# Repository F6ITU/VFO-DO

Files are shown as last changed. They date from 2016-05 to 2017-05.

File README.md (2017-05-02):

VFO-DO
RF Generator, Kicad project

VFO-DO est un générateur HF couvrant de quelques kHz à 100 MHz.

Il s'agit d'une idée originale de Gene Marcus W3PM/GM4YRE
publiée dans un article de la revue QEX

http://www.arrl.org/files/file/QEX_Next_Issue/2015/Jul-Aug_2015/Marcus.pdf

Ce projet Kicad n'est que la transposition dudit projet. 

La propriété intellectuelle et les droits de publication appartiennent respectivement 
à l'auteur et à la société de publication mentionnés

Ce projet offre à chaque débutant en électronique ou en radioélectricité les éléments nécessaires
à la construction d'une source de fréquence stable (précise au Herz près, puisque pilotée par l'étalon césium
de l'essaim de satellites GPS)... et surtout simple à construire -à assembler serait le terme le plus exact.

Cette réalisation peut servir d'équipement de terrain, là ou le déplacement d'un oscillateur asservi
-équipement fragile et coûteux- est inenvisageable. C'est surtout une approche simple pour piloter un petit SDR ou remplacer le VFO 
d'un appareil radio traditionnel

Plus d'informations sur le module oscillateur à base de SiLabs Si5351 
https://learn.adafruit.com/adafruit-si5351-clock-generator-breakout?view=all

une seconde source de ce module 

https://www.sv1afn.com/si5351a.html
Attention : ce dernier module n'est pas "pin compatible" avec le précédent

Le firmware originel de l'auteur 
http://www.knology.net/~gmarcus/Si5351/Si5351_vfo_v5.ino.zip

Un émetteur-récepteur WSPR conçu par l'auteur et utilisant ledit VFO-DO
http://www.knology.net/~gmarcus/Si5351/Si5351A_WSPR_XCVR.pdf

NB : le coût du générateur gravite aux environ des 30 euros. 
Attention, le bruit de phase d'un tel générateur est assez important, et ne peut 
rivaliser avec un GPS-DO traditionnel.

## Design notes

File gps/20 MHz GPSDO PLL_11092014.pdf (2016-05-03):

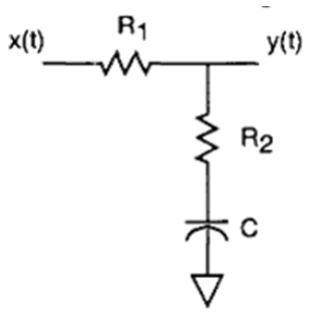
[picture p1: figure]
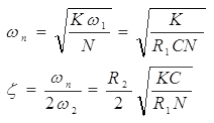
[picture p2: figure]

Pg 1 of 5 | K9IVB 11/08/2014

## 20 MHz GPSDO PLL

This is a preliminary document describing a GPSDO PLL that is to work with a ublox NEO-7 GPS receiver. Eventually it is desired to incorporate an Arduino uP to manage the startup with a simple display and a buffer board that will supply a suitable signal for reference frequency distribution employing 74HCT1G125 drivers.
The First PCB [1.7” x 1.7"] provides a PLL, an interface to the ublox GPS, an Arduino connection and a level converter for the serial communications. There is provision for a battery backup for the ublox NEO-7 that may be implemented in several different ways.
The PLL filter is described by the normal equations found below and exploited in a spreadsheet to be made available later.

### Second Order Passive Lead-Lag Filter

Also

is the phase detector gain in volts per radian | [(Power Supply/2])/[PI/2] = (Power Supply) / PI
is the VCO gain in radians per volt-second | 2*PI*(VCO Slope)
is the damping factor | [zeta]
is the natural frequency of the loop | = 2*PI*f
N is the loop frequency devisor
f is the loop frequency in Hz
K = | = [2 * (VCO Slope) * (Power Supply)] / N | NOTE: The PI's cancel
f | | C in F | | R2 | R1 | C in uF
0.16 | 1.005310 | 1.010647491 0.000470000 94.988610 | 2.575851 | 5,480.53 | 196,622.89 | 470
R1 | R2 | C | f
196000 | 6040 | 0.000470000 | 1.020842 | 1.448984 | 0.162472
K9IVB 10/18/2014
2 ωn | 1 τ | 2 τ

N

KV K p

Pg 2 of 5 | K9IVB 11/08/2014

After some additional reading, I have added another tab to the spreadsheet with the damping factor [zeta], ζ = 0.707. As it turns out you can achieve this condition by changing the R1 value to 200.0K and R2 to 3010 Ohms, = 0.7418; C still = 470 μF. Keeping the values of R1 =196.0K and C = 470 μF with R2 = 3.020 K by simply putting two of the 6.040K resistors in parallel and ζ = 0.7245, if you are interested in this value for ζ.
In my opinion, too many of the authors have put far too much emphasis on Floyd Gardner's mathematics and very little on the real world. Gardner shows best performance with ζ = 0.5 and has a "compromise" value of ζ = 0.707. These values reflect loops primarily used for an integer N synthesizer or signal recovery. We are doing neither and overshoot is undesirable, so ζ = 1.3 is number that I have chosen. Professor Long does differentiate in types of loops and suggests that even higher values of ζ may be used.
Another variable, of the few that are available is the loop natural frequency. This design can be considered a high gain loop, because of the VCO slope, the loop divisor N is only 10 and the reference frequency is 2.0MHz. When using reference frequencies of 1pps or up to 10KHz the loop natural frequency needs to be very small and preferably several orders of magnitude less than the reference frequency. I have chosen to keep this value small and still sub Hz at 0.16Hz. It is possible that it could be raised 10 to 100 times without affecting performance. Raising this value would bring the value of C near a level where a high performance film capacitor would be able to replace the Tantalum used for C1.
I will put more info on the web site after I get one built.

### References:

Best, Rolland E. Phase Locked Loops Design, Simulation, and Applications, Fifth Edition, New York, McGraw-Hill, 2003 Gardner, F.M., Phaselock Techniques, Second Edition, New York, NY, John Wiley and Sons, 1979.

### Long. Prof Steve, PLL_intro_594a_s05.pdf, UCSB/ECE Department, April 27, 2005

Stevens, Donald R., PHASE-LOCKED LOOPS FOR WIRELESS COMMUNICATIONS Digital, Analog and Optical

### Implementations, Second Edition, NEW YORK, KLUWER ACADEMIC PUBLISHERS, 2002

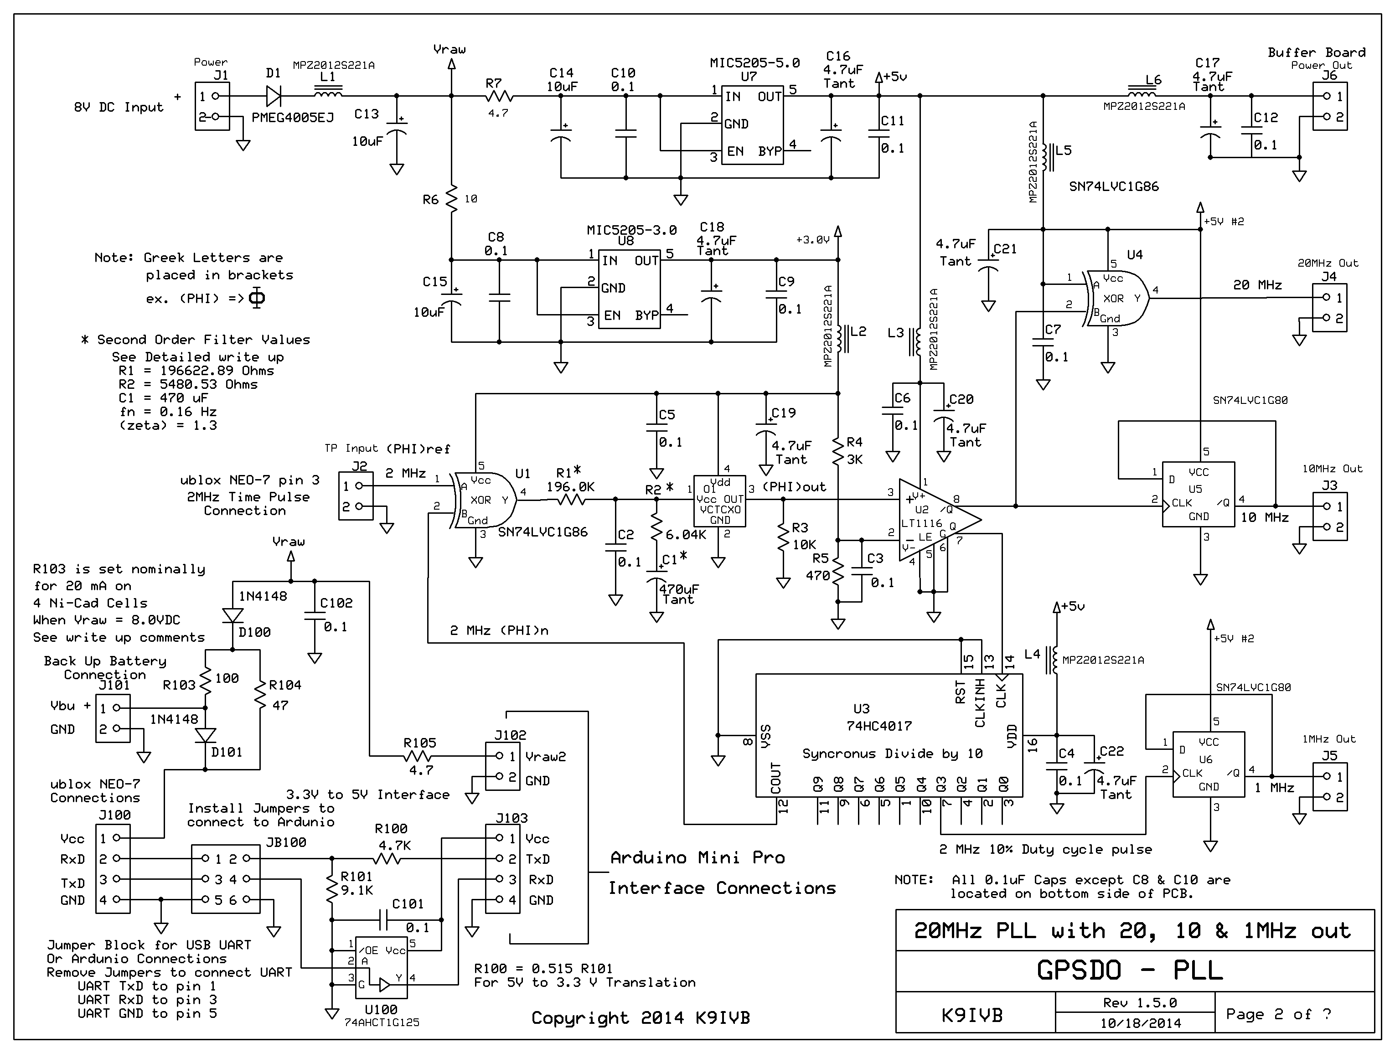
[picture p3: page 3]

Pg 3 of 5 | K9IVB 11/08/2014

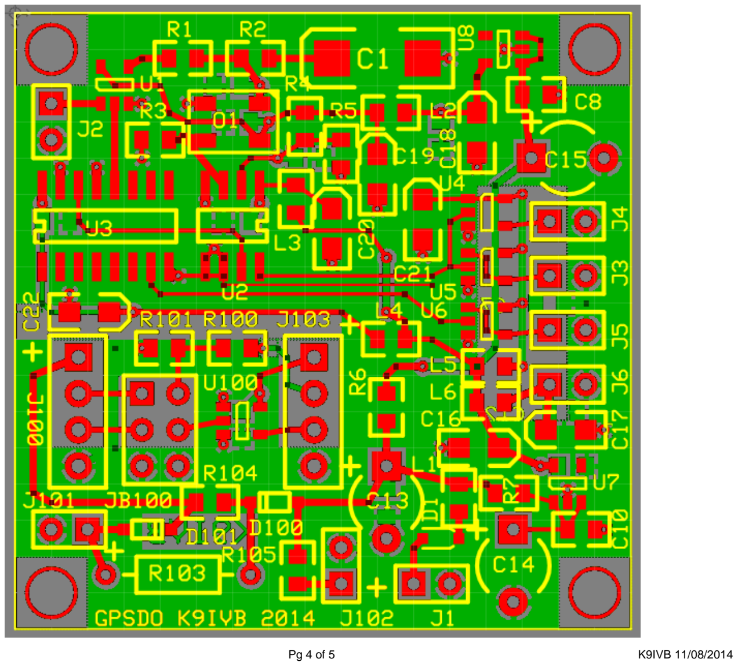
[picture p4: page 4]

Pg 4 of 5 | K9IVB 11/08/2014

Pg 5 of 5 | K9IVB 11/08/2014
GPSDO-PLL BOM | K9IVB 10/18/2014
Ref Des | Value | Description | Part Number | Mfg | PAD | Mouser | Qty
C1 | 470uF

Tantalum Capacitors -
Solid SMD 6.3V 470uF
10% "Y" Case | TAJY477K006RNJ | AVX | [7343] | 581-TAJY477K006RNJ | 1
C2, 3, 4, 5, 6,
7, 8, 9, 10,
11, 12, 101,
102 | 0.1

Multilayer Ceramic
Capacitors MLCC -
SMD/SMT 25volts 0.1uF
X7R 10% | C0805C104K3R | KEMET | [0805] | 80-C0805C104K3R | 13
C13, 14, 15 | 10uF | Aluminum Electrolytic
| | Capacitors - Leaded
| | 16volts 10uF 4X7mm
| | L/S=5.0mm Ammo
Crmp | EEA-GA1C100B | Panasonic 0.2" LS | 667-EEAGA1C100B | 3

C16, 17, 18,
19, 20, 21, 22 4.7uF Tant
| | Tantalum Capacitors -
| | Solid SMD 10V 4.7uF
10% "A" | T491A475K010AT | KEMET | 1206 | 80-T491A475K010 | 7
D1 | PMEG4005EJ | Schottky Diodes &
Rectifiers 40V 0.5A | PMEG4005EJ,115 | NXP | SOD-323 | 771-PMEG4005EJ-T/R | 1
D100, 101 | 1N4148 | 1N4148, SOD-323F | Fairchild | SOD-123 | 512-1N4148WS | 2
J1, 2, 3, 4, 5,
6, 101, 102 | | 1x2 .100" Header | | | | 8
J100, 103 | | 1x4 .100" Header | | | | 2
JB100 | | 2x3 .100" Header | | | | 1
L1, 2, 3, 4, 5,
6 | MPZ2012S221A | FERRITE CHIP 220
OHM 3A | MPZ2012S221A | [0805] | 810-MPZ2012S221A | 6
O1 | VCTCXO | ASVTX-09-20.000MHz-T | 815-ASVTX-09-20.0MT | 1
R1 | 196K | Thin Film Resistors -
| | SMD 0805 196Kohm
0.1% 25ppm | ERA-6AEB1963V | Panasonic | 667-ERA-6AEB1963V | 1
R2 | 6.040K | Thin Film Resistors -
| | SMD 0805 6.04Kohm
0.1% 25ppm | ERA-6AEB6041V | Panasonic | 667-ERA-6AEB6041V | 1
R3 | 10K | Thick Film Resistors -
| | SMD 1/10watts
10Kohms 5% | RK73B1JTTDD103J | KOA Speer [0805] | 660-RK73B1JTTDD103J | 1

Pg 6 of 5 | K9IVB 11/08/2014
R4 | 3K

Thin Film Resistors -
SMD 0805 1/8W
3Kohms 0.1% 0805 | ERA-6AEB302V | Panasonic [0805] | 667-ERA-6AEB302V | 1
R5 | 470

Thick Film Resistors -
SMD 1/8W 470ohm 1% | AC0805FR-07470RL | Yageo | [0805] | 603-AC0805FR-07470RL | 1
R6 | 10

Thick Film Resistors -
SMD 1/8W 10ohm 1% | AC0805FR-0710RL | Yageo | [0805] | 603-AC0805FR-0710RL | 1
R7, 105 | 4.7

Thick Film Resistors -
SMD 1/8W 4.7ohm 1% | AC0805FR-074R7L | Yageo | [0805] | 603-AC0805FR-074R7L | 2
R100 | 4.7K

Thick Film Resistors -
SMD 1/8W 4.7K ohm
1% | AC0805FR-074K7L | Yageo | [0805] | 603-AC0805FR-074K7L | 1
R101 | 9.1K

Thick Film Resistors -
SMD 0805 9.1Kohms
1% Tolerance | ERJ-6ENF9101V | Panasonic [0805] | 667-ERJ-6ENF9101V | 1
R103 | 100

Metal Film Resistors -
Through Hole 100ohm
1/4W 1% | MFR-25FRF52100R | Yageo | axial | 603-MFR-25FRF52100R | 1
R104 | 47

Thick Film Resistors -
SMD 1/8W 47ohm 1% | AC0805FR-0747RL | | [0805] | 603-AC0805FR-0747RL | 1
U1, 4 | SN74LVC1G86

Logic Gates 2 Input
XOR | TI | SOT-23-5 586-SN74LVC1G86DBVR | 2
U2 | LT1116 | LT1116CS8
| | Linear
Technology SOIC-8 | 1

alt

Analog Comparators
High Speed Comp | TL3116CD | TI | SOIC-8 | 595-TL3116CD
U3 | 74HC4017

Counter ICs 5-STAGE
JOHNSON DECADE
COUNTER [syncronus] | 74HC4017D,653 | NXP | SO-16 | 771-74HC4017D-T | 1
U5, 6 | SN74LVC1G80

Flip Flops Positive Edge
Trig | SN74LVC1G80DBVR | TI | SOT-23-5 595-SN74LVC1G80DBVR | 2
U7 | MIC5205-5.0

LDO Voltage Regulators
5V 150mA 1% Low
Noise LD | MIC5205-5.0YM5 TR | Micrel | SOT-23-5 998-MIC5205-5.0YM5TR | 1
U8 | MIC5205-3.0

LDO Voltage Regulators
3.0V 150mA 1% Low
Noise LD | MIC5205-3.0YM5 TR | Micrel | SOT-23-5 998-MIC5205-3.0YM5TR | 1
U100 | 74AHCT1G125

Buffers & Line Drivers
Tri-State Single Bus | SN74AHCT1G125DBVR TI | SOT-23-5 595-SNAHCT1G125DBVR | 1

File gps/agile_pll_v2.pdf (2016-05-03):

# VK3XDK Agile PLL V2

The VK3XDK “Agile PLL V2” is a convenient high performance frequency generator (synthesizer) able to directly produce accurate, stable and low noise signals at frequencies between 380MHz and 2000Mhz.

Typical uses are LO (local oscillator) and sub-multiplier LO generation, direct signal source, weak-harmonic style signal source (above 2000MHz)

## Features

-Simultaneously produces 2 separate frequencies (OutL / OutH)
-Output frequencies (OutH only) are easily “on the run” selectable by means of an on-board 4way binary switch. -TX/RX frequency offsets (OutH only) can be implemented (ie repeater/ duplex offsets)
-Outputs of up to 12dbm are available (Supplied MMIC amplifier/s installed)
-Power supply range of 7.5 to12V @ around 30mA (add around 40mA for each MMIC amplifier installed)
-Small in size, easy to mount and connect. ( 54mm X 48mm (excluding projections) , SMA input/Outputs)
-Standard frequencies and code can be re-configured (Picaxe 14M2 processor/ Basic programming)
-Uses the versatile si4133 “GT” (programmable reference divider version) odd and non integer MHz are now possible. -External 10MHz reference port (through panel SMA). Optional on-board 10MHz VTCXO available (ext/int Selectable)

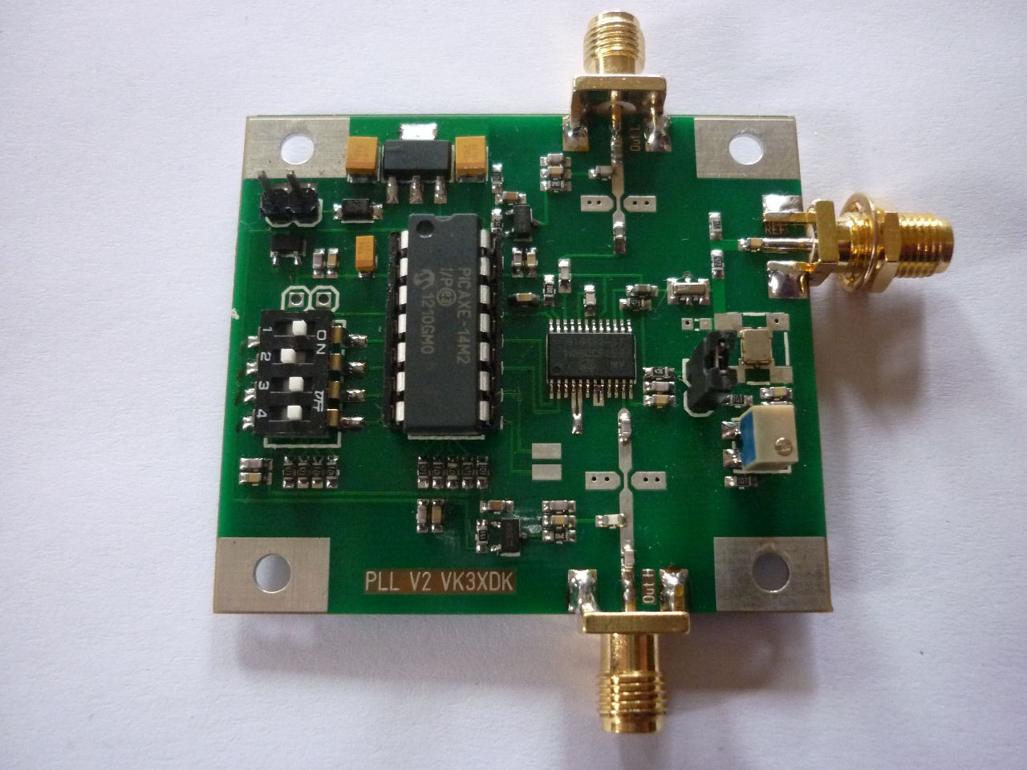
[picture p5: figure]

Optional on-board VTCXO version shown.

## Basics of operation

At the heart of the board is a SiLabs si4133 dual band RF synthesizer, the chip has 3 integrated VCO's
covering ranges of 62.5 to 1000MHz*, 750 to 1500MHz and 900 to 2000MHz*. The VCO's are PLL locked to a common reference signal of 10MHz (typically).

Serial control of the si4133 is achieved by use of a PICAXE 14M2, this processor was chosen because it provides programming simplicity for those that wish to alter frequencies/performance or incorporate special functions.
All Data (including frequencies) are stored within the PICAXE and are retained after loss of power.

As standard the board is pre-programmed with 17 commonly used frequencies and a further 16 frequencies available by use of the “special function Jumper (SF JMP)” (33 separate Frequencies in total)
OutL - Fixed at 404MHz.
OutH - 16 Frequencies BankA / 16 Frequencies BankB

16 “BankA” frequencies are available and are selected by an on-board 4way SMD. A further 16 frequencies (BankB) are enabled by shorting the “SF JMP” Pins. As Standard BankB=BankA-1MHz, the “SF JMP” can be a remotely mounted mechanical or electronic switch.

It is important to understand the behavior of the VCO's when using the standard (supplied) on-board code.
The si4133 has 3 integrated VCO's covering three frequency ranges,each VCO's center frequency is set with an L-C type oscillator network where the “L” part of the network is external to the chip and adjustable.
-The lower frequencies use a chip-type inductor (L2)
-The mid mid and high frequencies use PCB trace inductors (L5 and L6 respectively), the inductance’s can be adjusted by moving the respective “solder-blob short”.

Lowering the inductance value raises the center frequency of that particular VCO.

The si4133 has special compensating circuitry which allows the VCO's to lock at a large range of frequencies around the center frequency, continuous coverage (300 to 2000MHz) is NOT available due to the limited range of each VCO and therefore the VCO's should be centered around the frequencies of most interest. (some slight adjustment may be needed in some cases.)

Large temperature variations, vibrations and mechanical shock can affect the VCO's. If needed - temperature changes can normally be compensated for by re-initializing the board (ie re-powering or switching/re-switching frequencies).
It is suggested that “common sense” be applied when choosing the boards mounting location (ie away from fans, power devices, strong interfering signals etc.)

## Optional MMIC Amplifiers (supplied)

The output level of both OUT L and OUT H is around -2dbm. For higher output/s there are 2X ERA2 (Minicircuits) MMIC amplifiers. Installation will typically boost the output/s to around 10-12dbm (10-16mW). The amplifiers can be installed on either or both outputs but for best overall performance install only when necessary.
-Installation of these devices requires cut/s to the PCB trace and soldering (please see layout diagram).
-Each MMIC amplifier (when installed) consumes around 40mA

*The lower frequencies (below around 380MHz) require a programmable output division. *1800MHz to 2000MHz is out of specifications but in practice functions very well.

## Reference Signal

The standard board uses an off-board (or optional on-board) 10MHz reference signal, 10MHz has been chosen due to it's popularity and availability. Other reference frequencies can be used with modified software.

External:
Perhaps the most critical part of the system, the often stated “rubbish in- rubbish out” holds very true with this and most other PLL systems, the board does have an on-board reference filter that can help- BUT it is best to have a good reference in the first place.
-A low phase-noise, low harmonic sine-wave reference of 7 to 20dbm ( 5mW to 100mW) has been found to be the best.

Other wave types including “clipped sine-wave” and high slew-rate “square-wave ” can be used but are not recommended.

-The boards external reference input impedance is 50ohm.

Quality “Oven” (OCXO) or GPS/ Rubidium oscillators when combined with the VK3XDK Agile PLL V2 can can easily produce sub-Hz stability over the boards range.

Please note:
The external reference signal needs to be present and reasonably settled during the PLL data loading/ initialization.
A pre-programmed and configurable software start-up delay (around 2sec) has been incorporated and is adequate for most “switch-on together” instances, however a slow settling external reference may need a longer delay (OR turn-on sequencing.)

Internal (optional on-board):
An optional on-board VTCXO (voltage/ Temperature controlled oscillator) is available and proves very convenient and more than adequate for many uses. The frequency is able to be finely adjusted by use of an on-board 11Turn potentiometer.

The on-board oscillator can (and needs to) be turned off when an external reference is connected. This is done by removing the “VCXO EN” PCB jumper. The jumper could be changed to a remote switch for convenience.

The currently available on-board oscillator is type: ECS Inc, part number VC-TXO-23SM-100-B
Frequency stability is specified as ±2.5ppm
In a standard (work bench) environment my 24hour tests have shown less than 200Hz drift @ 1656MHz. (most of which is during the initial 10Min.warmup)

## Notes

SMD components (especially capacitors) are intolerant to PCB flex- Care needs to be taken with board mounting and when connecting/ disconnecting.

The primary voltage regulator is type LM340MP-5.0 (5V)

## Standard Frequencies

### BankA (OutH)

No. | Switch Pos. | Frequency (MHz) and typical use. | Locking (as sent) | VCO
1 | 0000 | 1104.00 (X3 for 3312MHz Injection (3456 Transverter / 144IF)) | YES | M
2 | 0001 | 1152.00 (1296Mhz Transverter / 144MHz IF ) and many other options (see below) | YES | M
3 | 0010 | 1242.00 (X8 for 9936MHz Injection (10368 Transverter / 432IF) | YES | M
4 | 0011 | 1278.00 (X8 for 10224Mhz Injection (10368 Transverter / 144IF) | YES | M
5 | 0100 | 1296.00 (1296 MHz Signal source, X8 for 10368 signal source) | YES | M
6 | 0101 | 1332.00 (X4 for 5328MHz Injection (5760 Transverter / 432IF) | YES | M
7 | 0110 | 1336.00 (X18 for 24048MHz Signal source) | YES | M
8 | 0111 | 1344.00 (X18 for 24192MHz Signal source) | YES | M
9 | 1000 | 1484.00 (X2 for 2968MHz Injection (3400 Transverter / 432IF) | NO* | H
10 | 1001 | 1512.00 (X2 for 3024MHz Injection (3456 Transverter / 432IF) | NO* | H
11 | 1010 | 1656.00 (X6 for 9936MHz Injection (10368 Transverter / 432IF) , X2 for 3312MHz (3456 Transverter / 144IF)) | YES | H
12 | 1011 | 1700.00 (X2 for 3400MHz Signal source) | YES | H
13 | 1100 | 1776.00 (X3 for 5328MHz Injection (5760 Transverter / 432IF) | YES | H
14 | 1101 | 1872.00 (X3 for 5616MHz Injection (5760 Transverter / 144IF) | YES | H
15 | 1110 | 1920.00 (X3 for 5760MHz Signal source) | YES | H
16 | 1111 | 1971.00 (1971MHz Injection (2403 Transverter / 432IF) | YES | H

### BankB (OutH) (SF JMP shorted)

No. | Switch Pos. | Frequency (MHz) | Locking (as sent) | VCO
1 | 0000 | 1103.00 (BankA – 1MHz) (independently programmable) | YES | M
2 | 0001 | 1151.00 (BankA - 1MHz) (independently programmable) | YES | M
3 | 0010 | 1241.00 (BankA - 1MHz) (independently programmable) | YES | M
4 | 0011 | 1277.00 (BankA - 1MHz) (independently programmable) | YES | M
5 | 0100 | 1295.00 (BankA - 1MHz) (independently programmable) | YES | M
6 | 0101 | 1331.00 (BankA - 1MHz) (independently programmable) | YES | M
7 | 0110 | 1335.00 (BankA - 1MHz) (independently programmable) | YES | M
8 | 0111 | 1343.00 (BankA - 1MHz) (independently programmable) | YES | M
9 | 1000 | 1483.00 (BankA - 1MHz) (independently programmable) | NO* | H
10 | 1001 | 1511.00 (BankA - 1MHz) (independently programmable) | NO* | H
11 | 1010 | 1655.00 (BankA - 1MHz) (independently programmable) | YES | H
12 | 1011 | 1699.00 (BankA - 1MHz) (independently programmable) | YES | H
13 | 1100 | 1775.00 (BankA - 1MHz) (independently programmable) | YES | H
14 | 1101 | 1871.00 (BankA - 1MHz) (independently programmable) | YES | H
15 | 1110 | 1919.00 (BankA - 1MHz) (independently programmable) | YES | H
16 | 1111 | 1970.00 (BankA - 1MHz) (independently programmable) | YES | H

OutL -fixed at 404MHz (432 Transverter (28MHz IF). VCO L (L2)

1152 MHz options: X2 for 2304MHz, X3 3456MHz, X5 5760MHz, X9 10368MHz, X21 24192MHz

* 1483/1484MHz and 1511/1512MHZ are normally not locking as sent, adjustments to VCO H will usually be needed if these frequencies are required. (L6 increased). 1919MHz and 1970MHz will likely not lock in this case.

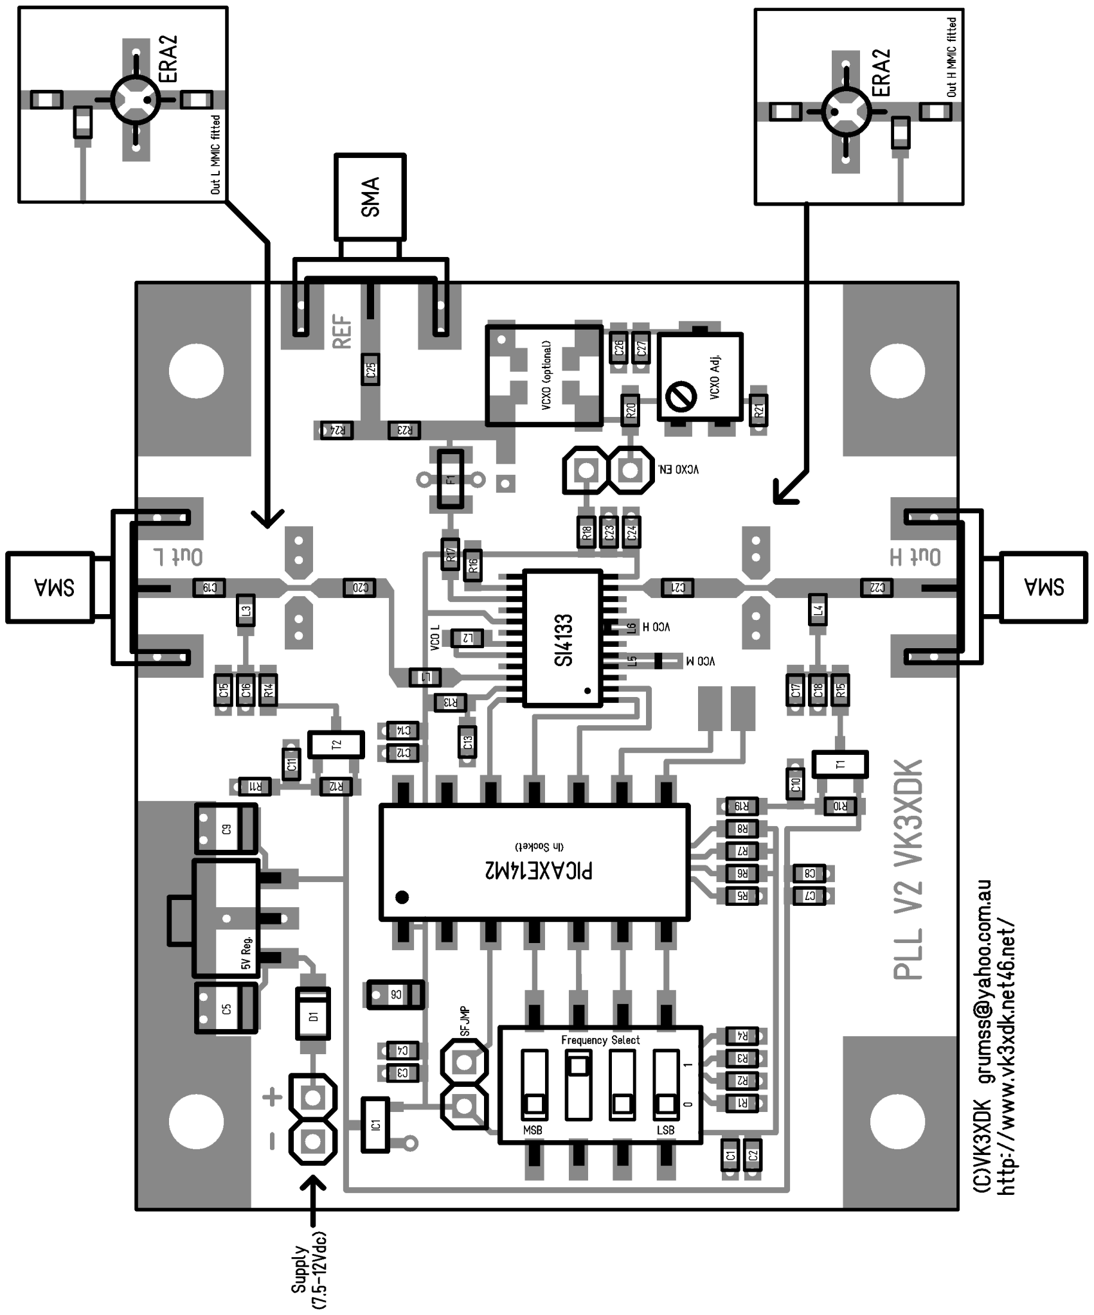
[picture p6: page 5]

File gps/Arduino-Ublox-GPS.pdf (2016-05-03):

http://www.instructables.com/id/Arduino-Ublox-GPS/technology (http://www.instructables.com/tag/type-id/category-technology/) workshop (http://www.instructables.com/tag/type-id/category-workshop/) craft (http://www.instructables.com/tag/type-id/category-craft/) home (http://www.instructables.com/tag/type-id/category-home/) food (http://www.instructables.com/tag/type-id/category-food/) play (http://www.instructables.com/tag/type-id/category-play/) outside (http://www.instructables.com/tag/type-id/category-outside/) costumes (http://www.instructables.com/tag/type-id/category-costumes/)

# Arduino Ublox GPS

by msuzuki777 (http://www.instructables.com/member/msuzuki777/?utm_source=pdf&utm_campaign=title) on June 11, 2014

Table of Contents

Author:msuzuki777
Lazy Old Geek

## Intro: Arduino Ublox GPS

So this Lazy Old Geek (L.O.G.) was looking for a GPS for an Arduino project. Well, I found this UBLOX-NEO-6M GPS on ebay:

http://www.ebay.com/itm/Ublox-NEO-6M-GPS-Module-with-EEPROM-and-Built-in-Active-Atenna-APM2-5-APM2-0-Com-/251548034492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 (http://www.ebay.com/itm/Ublox-NEO-6M-GPS-Module-with-EEPROM-and-Built-in-Active-Atenna-APM2-5-APM2-0-Com-/251548034492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)

WARNING: I think I actually ordered this one but the one I got was slightly different. The connectors were not as shown but centered on the PCB.

The antenna is attached to the PCB with a little snap on coax connector. It can be carefully lifted off to disconnect.

The metal shield on the antenna should be pointed down. You can buy cases for the antenna. You can also use double sticky tape to stick the antenna to the bottom of the GPS pcb.

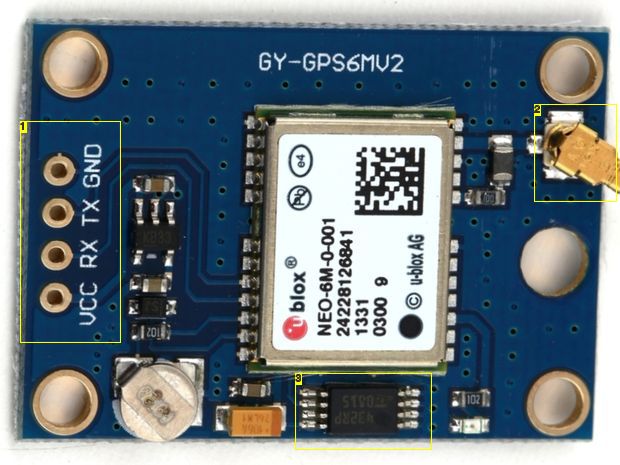
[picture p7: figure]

Image Notes
1. Connector is centered on PCB
2. Antenna snaps on
3. EEPROM

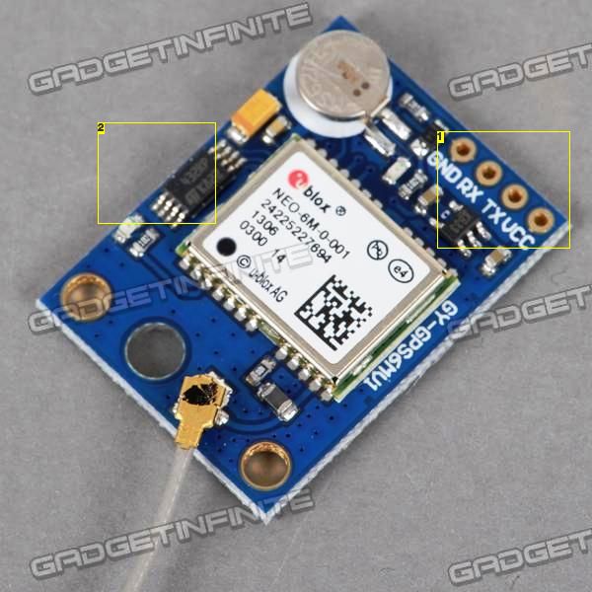
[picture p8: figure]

Image Notes
1. Connector is offset to one side
2. This is the picture shown in the ebay listing

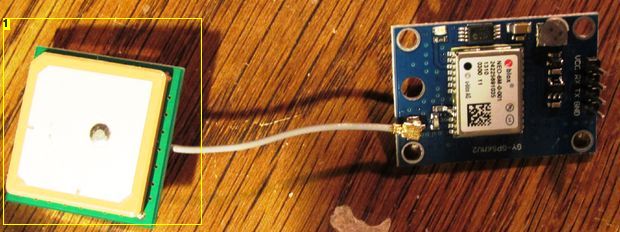
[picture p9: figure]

Image Notes
1. Antenna

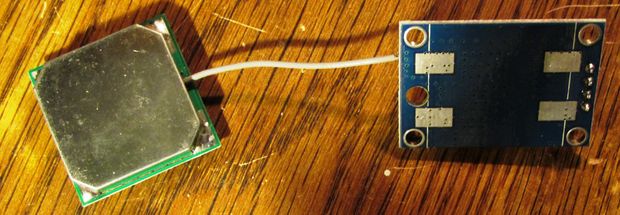
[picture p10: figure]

## Step 1: Arduino

The Ublox NEO-6M GPS is fairly easy to use with Arduino.

There are a few options for Arduino GPS libraries. I chose TinyGPSPlus:

http://arduiniana.org/libraries/tinygpsplus/

There is also a TinyGPS, I believe written by the same person.

You also need to include SoftwareSerial.h to use this library.

Hardware: Some of the UBLOX NEO-6M modules come with a loose 4pin header. These can be soldered in with pins going in either direction. Unfortunately, I put some on the wrong side for another project and had to unsolder them and put some new ones on the other side.

TIP: I saw a picture of someone using these types of clips (see picture) so that you don’t have to decide ahead of time.

Connect the four pins from UBLOX to an Arduino as follows:

Ublox - Arduino

GND - GND

TX - Digital pin (D4 in the DeviceExample)

RX - Digital pin (D3 in the DeviceExample)

Vcc - 5Vdc or 3.3Vdc

Now you can start up your Arduino environment and run the TinyGPSPlus example called DeviceExample.

In the sketch, change GPSBaud = 9600

Should work fine.

TIP: Here is one thing you need to remember, the TX pin from the UBLOX goes to the RX pin of the Arduino and vice versa.

TECHNOBABBLE: The explanation for this is not so bad. TX stands for Transmit where data is sent out. RX stands for Receive where data comes in.

So the UBLOX-TX sends data to the Arduino-RX

And the UBLOX-RX receives data from the Arduino-TX

HINT: While the standard is to label pins from the perspective of the device, this is not always the case.

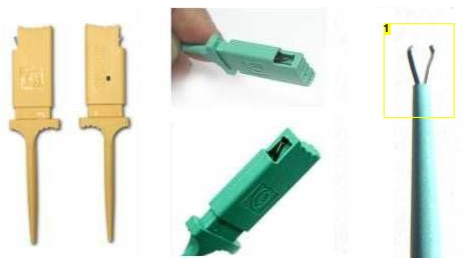
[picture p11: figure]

Image Notes
1. Could clip to header connector

## Step 2: U-center

So this works pretty good.

But I’m a Geek and the UBLOX-NEO-6M supports something called WAAS, Wide Area Augmentation System.

So standard commercial GPS are not really precise. A particular reading may be several meters off. Using WAAS is supposed to improve the precision.

Ublox is a Swiss company. Here’s their website:

http://www.u-blox.com

Documentation for this product is a little hard to find:

http://www.u-blox.com/en/download/documents-a-resources/u-blox-6-gps-modules-resources.html

but everything under NEO-6 series should be applicable.

Okay, now I’m a Geek, but most of this stuff is over my head. So I did a lot of Internet searching and guessing.

Most GPSs are basically serial devices. Most are set for a baud rate of 4800 (these Ubloxs are set for 9600). They use a standard called NMEA 0183:

http://en.wikipedia.org/wiki/NMEA_0183

I think most GPSs when powered up will automatically start sending out data typically every two second.

Okay, according to the U-blox6_ReceiverDescriptionProtocolSpec, the Ublox supports both NMEA 0183 (that’s why it works with TinyGPS) and their own UBX protocol.

NOTE: I think WAAS is only used in the U.S. I think Europe has or will have something similar.

I haven’t found any standard way of activating WAAS or even determining if it is activated. But Ublox has some PC software called: u-center

http://www.u-blox.com/en/evaluation-tools-a-software/u-center/u-center.html

This is really nice free software and even has a manual but for this Lazy Old Geek it’s still very confusing.

Well, the first thing I had to figure out was how to hook it up to the Ublox-Neo-6M GPS.

So PCs and laptops no longer have serial ports (besides the Ublox is not RS-232 compatible) but they have USB ports and I have several PL2303 USB modules that convert serial to USB. I hooked mine up as follows:

PL2303 - Ublox

Gnd - Gnd

Rxd - Tx

Txd - Rx

3.3V - Vcc

NOTE: Notice that RXD connects to TX and Txd connects to RX as previously discussed.

HINT: You can alternately connect the Ublox Vcc to 5V.

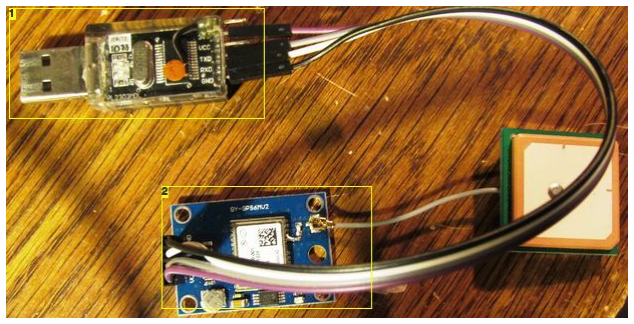
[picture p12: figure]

Image Notes
1. PL2303 module
2. Ublox-Neo-6M GPS module

## Step 3: Using u center

PROBLEM: So I connected my Ublox-neo-6m to my PL2303, plugged the PL2303 into a USB port on my laptop and powered it up. Well, Windows started up fine, but my mouse movement was erratic and I couldn’t control it. Well, (I’m pretty sure), the laptop thinks I have a serial mouse connected.

SOLUTION: Well, first, I tried disconnecting the PL2303 until after the laptop loaded up Windows. Still did the same thing.

So what I have to do is leave the PL2303 connected but disconnect power to the Ublox. Then power up laptop to Windows, then connect power to the Ublox.

Hopefully, you won’t have this problem.

Okay, so once the Ublox has power it takes a minute or two for it to get started. (I guess this is called a cold start). The green LED on the Ublox will start flashing.

Click on the Ucenter icon.

Click on Receiver Port Select the COM # that your PL2303 comes up as. Mine is COM 5.

Click on Receiver Baudrate Select 9600.

You should see some activity on the right side of the screen(see picture)

Note: on the bottom, it shows Com5 9600 ublox 6 and NMEA

The screens in the middle show satellite information.

The screen on the right shows latitude, longitude and altitude.

Note: FixMode is 3D/DGPS.

Differential Global Positioning System (DGPS) means WAAS is working.

HINT: Especially indoors, this may just say 3D. Also the DGPS may take several minutes before it displays.

Configuring the Ublox Neo-6M. The way I did it is:

view - configuration view(see next picture)

NAV5

Nav Mode

Dynamic Model: Pedestrian

Fix Mode: Auto 2D/3D

UTC Standard: USNO(GPS) {Doesn’t save??}

Click on send lower left corner

NOTE: Pedestrian mode probably won’t make much difference but for my application it is more accurate. See ProductSpec

view-configuration view (see next picture)

Subsystem: Enabled

Services: Ranging

Apply SBAS Correction data

Number: 3

PRN Codes: WAAS

Click on send lower left corner

NOTE: This forces WAAS. The more general term is SBAS(Space Based Augmentation Systems)

NOTE: There are other configurations you can change like Baud rate and sampling rate.

Okay, the two sends above send it to the Ublox GPS but it doesn’t save it. To save, do the following.

(see next picture)

Main menu

Receiver

Action

Save config

This saves it to (I believe) the EEPROM on the Ublox-neo-6m pcb.

WARNING: Close ‘u-center’ before disconnecting GPS . Otherwise u-center will lock up and you will get a Blue screen.

The next picture shows the Deviation Map. Each GPS sampling shows in yellow, which changes to green when the next sampling occurs. This shows the readings have drifted about two meters.

U-center has a lot of other features, one I like it Google Earth. It will show the GPS location on Google Earth.

So that’s what I’ve learned about the Ublox-neo-6m so far.

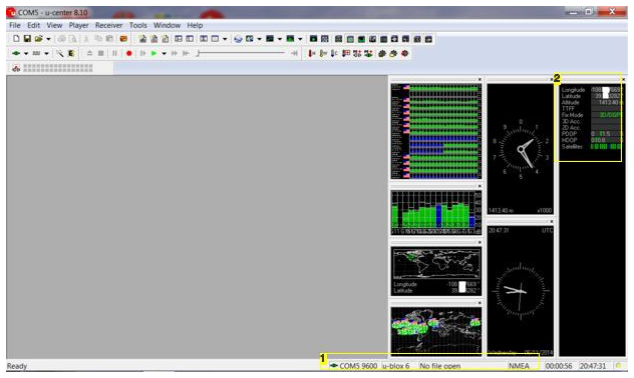
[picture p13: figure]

Image Notes
1. Describes USB connection and protocol
2. Latitude, Longitude, Altitude and Fix Mode

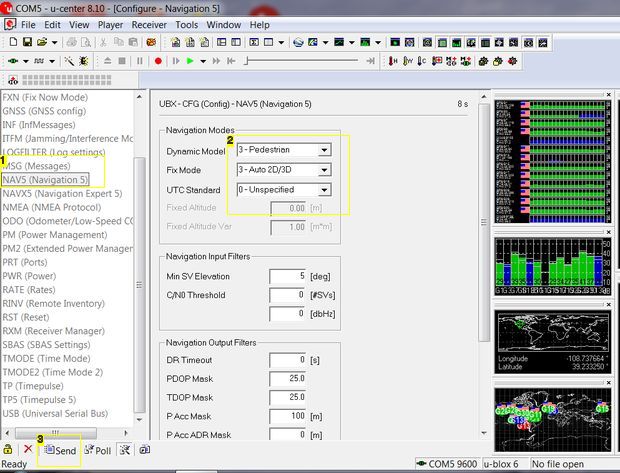
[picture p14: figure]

Image Notes
1. Select NAV5
2. I chose Pedestrian model
3. Send to GPS module

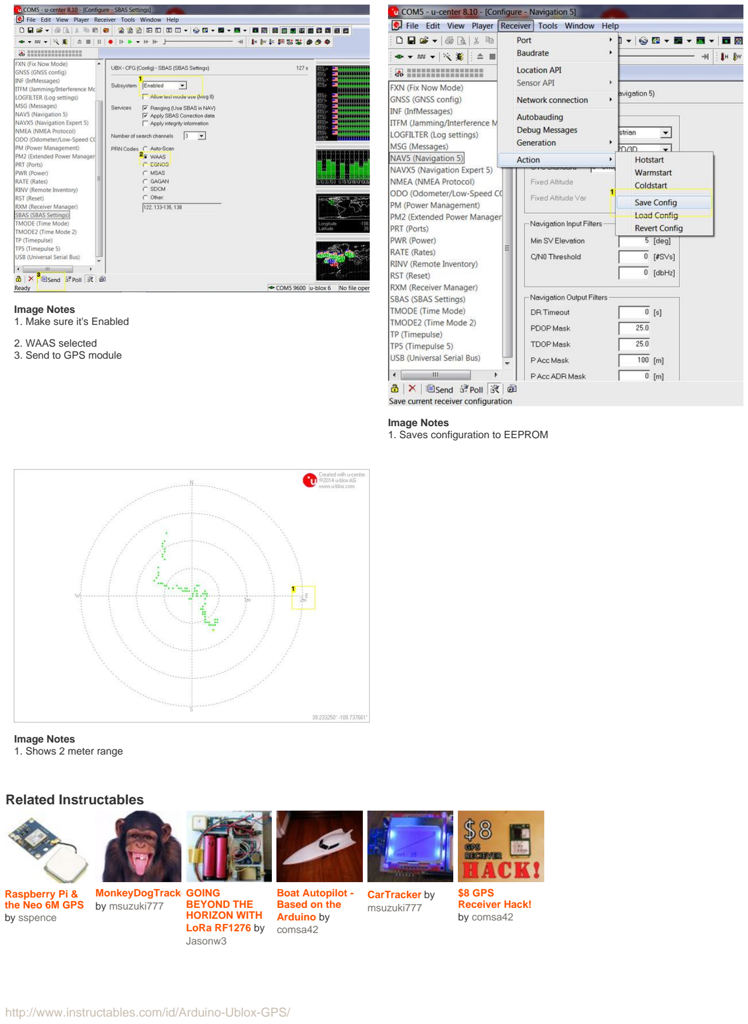
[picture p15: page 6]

Image Notes
1. Make sure it's Enabled
2. WAAS selected
3. Send to GPS module

Image Notes
1. Saves configuration to EEPROM

Image Notes
1. Shows 2 meter range

## Related Instructables

Raspberry Pi &
the Neo 6M GPS (http://www.instructables.com/id/Raspberry-Pi-the-Neo-6M-GPS/?utm_source=pdf&utm_campaign=related)
by sspence (http://www.instructables.com/member/sspence/?utm_source=pdf&utm_campaign=related)

MonkeyDogTracker (http://www.instructables.com/id/MonkeyDogTracker/?utm_source=pdf&utm_campaign=related)
by msuzuki777 (http://www.instructables.com/member/msuzuki777/?utm_source=pdf&utm_campaign=related)

GOING
BEYOND THE
HORIZON WITH
LoRa RF1276 (http://www.instructables.com/id/GOING-BEYOND-THE-HORIZON-WITH-LoRa-RF1276/) by
Jasonw3 (http://www.instructables.com/member/Jasonw3/?utm_source=pdf&utm_campaign=related)

Boat Autopilot -
Based on the
Arduino (http://www.instructables.com/id/Boat-Autopilot/?utm_source=pdf&utm_campaign=related) by
comsa42 (http://www.instructables.com/member/comsa42/?utm_source=pdf&utm_campaign=related)

CarTracker (http://www.instructables.com/id/CarTracker/?utm_source=pdf&utm_campaign=related) by
msuzuki777 (http://www.instructables.com/member/msuzuki777/?utm_source=pdf&utm_campaign=related)

$8 GPS
Receiver Hack! (http://www.instructables.com/id/8-GPS-Receiver-Hack/?utm_source=pdf&utm_campaign=related)
by comsa42 (http://www.instructables.com/member/comsa42/?utm_source=pdf&utm_campaign=related)

Advertisements

## Comments

26 comments | Add Comment (http://www.instructables.com/id/Arduino-Ublox-GPS/?utm_source=pdf&utm_campaign=comments#comments)
captclearleft (http://www.instructables.com/member/captclearleft/?utm_source=pdf&utm_campaign=comments) says: | Jul 28, 2015. 7:36 AM REPLY (http://www.instructables.com/id/Arduino-Ublox-GPS/?utm_source=pdf&utm_campaign=comments#DISCUSS)
Great Job,

Some basic help for others that I learned while hooking this up.

This unit does not have a power led.

When first powering up your Ublox NEO-6M you may see nothing for a period of time. After about 10 min the only led(green on mine) will begin to flash about once a second.

If you are connecting through Software Serial on an Arduino,

Read the tutorial and pay attention to how your wire the RX, and TX lines. Its just like hardware serial. Rx to Tx, and Tx to Rx...

Just like the tutorial above states...

I hooked mine up to a regular Arduino Uno(r3) 5v, and have had no issues....

Hope this helps...

msuzuki777 (http://www.instructables.com/member/msuzuki777/?utm_source=pdf&utm_campaign=comments) says: | Jul 28, 2015. 9:48 AM REPLY (http://www.instructables.com/id/Arduino-Ublox-GPS/?utm_source=pdf&utm_campaign=comments#DISCUSS)
Thanks for the Tips. Yes it is hard to tell if it's working with the delayed LED. I do like these NEO-6Ms.

LOG

matejj (http://www.instructables.com/member/matejj/?utm_source=pdf&utm_campaign=comments) says: | Nov 11, 2014. 3:45 PM REPLY (http://www.instructables.com/id/Arduino-Ublox-GPS/?utm_source=pdf&utm_campaign=comments#DISCUSS)
The Neo-6 documentation says absolute maximum supply voltage is 3.6V. Why are you so confident 5V won't destroy it?
msuzuki777 (http://www.instructables.com/member/msuzuki777/?utm_source=pdf&utm_campaign=comments) says: | Nov 11, 2014. 5:54 PM REPLY (http://www.instructables.com/id/Arduino-Ublox-GPS/?utm_source=pdf&utm_campaign=comments#DISCUSS)
The NEO-6 module does have a maximum of 3.6V but the module I'm using is rated for 3-5Vdc. It has a 3.3V regulator on the board.

LOG

tmatz81 (http://www.instructables.com/member/tmatz81/?utm_source=pdf&utm_campaign=comments) says: | Apr 26, 2015. 2:02 PM REPLY (http://www.instructables.com/id/Arduino-Ublox-GPS/?utm_source=pdf&utm_campaign=comments#DISCUSS)
Don't forget to hook up a level converter to the Rx and Tx to go down to 3,6V. Or at least hookup a 10kOhm resistor to the Rx side of the NEO-6M module. As you can see in this diagram, the Rx pin of the GPS is not level shifted on the board. http://www.uctronics.com/ebayproductpic/GYGPS6MV1_SCH.jpg
msuzuki777 (http://www.instructables.com/member/msuzuki777/?utm_source=pdf&utm_campaign=comments) says: | Apr 26, 2015. 4:29 PM REPLY (http://www.instructables.com/id/Arduino-Ublox-GPS/?utm_source=pdf&utm_campaign=comments#DISCUSS)
Actually, that is not necessary in this case. The USB to serial converter that I am using has a PL2303 chip. The Tx and Rx pins are actually 3.3V levels already so no level conversion is necessary.

The original USB-BUB also has a jumper that select either 5V or 3.3V serial voltage levels.

LOG

AmandaS11 (http://www.instructables.com/member/AmandaS11/?utm_source=pdf&utm_campaign=comments) says: | Apr 25, 2015. 12:04 PM REPLY (http://www.instructables.com/id/Arduino-Ublox-GPS/?utm_source=pdf&utm_campaign=comments#DISCUSS)
Hello from Brazil!

I think I have a problem: I working on a synchronization of a phasor measurement unit and so I bought two of this Ublox Neo board. But now I'm seeing that it don't have one pin for PPS like another models from dx.com ... :'(

But I hope that I can adapte this board for it. Do you think it's possible?? Cause I don't have money neither time to buy another and wait arrive... Please help.

msuzuki777 (http://www.instructables.com/member/msuzuki777/?utm_source=pdf&utm_campaign=comments) says: | Apr 25, 2015. 12:29 PM REPLY (http://www.instructables.com/id/Arduino-Ublox-GPS/?utm_source=pdf&utm_campaign=comments#DISCUSS)
I am not quite sure what you are talking about but I'm assuming you mean what ublox calls the Time Pulse. This is used to blink the module LED. I marked it's location on the picture below. You would have to solder a wire to this spot. Hopefully, this will do what you need.

LOG

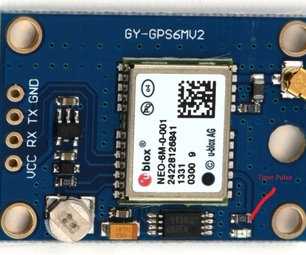
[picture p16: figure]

AmandaS11 (http://www.instructables.com/member/AmandaS11/?utm_source=pdf&utm_campaign=comments) says: | Apr 25, 2015. 4:30 PM REPLY (http://www.instructables.com/id/Arduino-Ublox-GPS/?utm_source=pdf&utm_campaign=comments#DISCUSS)
Thank you, I think you're right. Exactly, PPS (pulse per second) is the Time Pulse, which permits time synchronization in long distances.
msuzuki777 (http://www.instructables.com/member/msuzuki777/?utm_source=pdf&utm_campaign=comments) says: | Apr 25, 2015. 5:53 PM REPLY (http://www.instructables.com/id/Arduino-Ublox-GPS/?utm_source=pdf&utm_campaign=comments#DISCUSS)
Hope that works. It's pin 3 of the NEO-6M module. I think it's even selectable in software but don't know if U-center supports it.

LOG

ZubairK3 (http://www.instructables.com/member/ZubairK3/?utm_source=pdf&utm_campaign=comments) says: | Apr 15, 2015. 11:00 AM REPLY (http://www.instructables.com/id/Arduino-Ublox-GPS/?utm_source=pdf&utm_campaign=comments#DISCUSS)
hello guys,,

i am facing problem in loading map while connecting UBLOX gps with multi wii...guys i have to submit my project please i would be very thankfull if someone could send me the correct aurdino code to interface UBLOX gps with multiii wii..

my email id is :- kzbr1993@gmail.com

thanks

msuzuki777 (http://www.instructables.com/member/msuzuki777/?utm_source=pdf&utm_campaign=comments) says: | Apr 15, 2015. 11:50 AM REPLY (http://www.instructables.com/id/Arduino-Ublox-GPS/?utm_source=pdf&utm_campaign=comments#DISCUSS)
Sorry I never used multiwii.

LOG

nathan.marchuk.3 (http://www.instructables.com/member/nathan.marchuk.3/?utm_source=pdf&utm_campaign=comments) says: | Mar 23, 2015. 8:24 PM REPLY (http://www.instructables.com/id/Arduino-Ublox-GPS/?utm_source=pdf&utm_campaign=comments#DISCUSS)
i follow all these steps exactly to change my baud rate to 115200 but u-center is still reading data on it at 4800 baud? please help im trying to configure this to read out ubx protocol in 115200 baud so that i can connect it to my i2c nav board and then connect to my multiwii for gps RTH functions :S
doug.carnahan1 (http://www.instructables.com/member/doug.carnahan1/?utm_source=pdf&utm_campaign=comments) says: | Mar 30, 2015. 10:45 PM REPLY (http://www.instructables.com/id/Arduino-Ublox-GPS/?utm_source=pdf&utm_campaign=comments#DISCUSS)
I believe you will have to use the u-center to modify the baud rate as it has to do with the firmware in the chip. The ublox could possibly be on a module that runs on some different firmware as I have seen these mounted to several different boards. There are many tutorials here and on youtube for this task.
msuzuki777 (http://www.instructables.com/member/msuzuki777/?utm_source=pdf&utm_campaign=comments) says: | Mar 23, 2015. 9:28 PM REPLY (http://www.instructables.com/id/Arduino-Ublox-GPS/?utm_source=pdf&utm_campaign=comments#DISCUSS)
So what kind of GPS module are you using? If you're using the NEO-6M like in my example the baud rate is fixed at 9600. I don't think this is configurable unless you change the voltages on a couple of pins (probably by cutting and jumpering) and according to my documentation, the NEO-6M doesn't support 115200.

If you're using a different GPS, you will have to look at the documentation for it.

LOG

doug.carnahan1 (http://www.instructables.com/member/doug.carnahan1/?utm_source=pdf&utm_campaign=comments) says: | Mar 28, 2015. 8:17 PM REPLY (http://www.instructables.com/id/Arduino-Ublox-GPS/?utm_source=pdf&utm_campaign=comments#DISCUSS)
Im assuming I wont need the I2c chip if im connecting directly to arduino?
msuzuki777 (http://www.instructables.com/member/msuzuki777/?utm_source=pdf&utm_campaign=comments) says: | Mar 30, 2015. 8:48 PM REPLY (http://www.instructables.com/id/Arduino-Ublox-GPS/?utm_source=pdf&utm_campaign=comments#DISCUSS)
I am not using I2C in this project.

LOG

doug.carnahan1 (http://www.instructables.com/member/doug.carnahan1/?utm_source=pdf&utm_campaign=comments) says: | Mar 30, 2015. 10:38 PM REPLY (http://www.instructables.com/id/Arduino-Ublox-GPS/?utm_source=pdf&utm_campaign=comments#DISCUSS)
The one I purchased from ebay stated it was needed to communicate with arduino ,Im assuming they mistook it for one of the flight controller boards used with open hardware drones. Either way I have a couple happily running gps modules that I tested using this tutorial. I am now in the process of modifying my traffic management application, thanks!
taylor.d.shields (http://www.instructables.com/member/taylor.d.shields/?utm_source=pdf&utm_campaign=comments) says: | Mar 20, 2015. 12:28 PM REPLY (http://www.instructables.com/id/Arduino-Ublox-GPS/?utm_source=pdf&utm_campaign=comments#DISCUSS)
Hey there! When I run this setup on the Arduino Serial, the device doesnt send any data. It registers the GPS, and starts spitting out "stars" (*) in place of where coordinates would be.... What could this be?
msuzuki777 (http://www.instructables.com/member/msuzuki777/?utm_source=pdf&utm_campaign=comments) says: | Mar 20, 2015. 1:17 PM REPLY (http://www.instructables.com/id/Arduino-Ublox-GPS/?utm_source=pdf&utm_campaign=comments#DISCUSS)
I'm guessing but make sure the Serial port baud rate is set to the same as the sketch. It sounds like they're different.

LOG

AhmadE2 (http://www.instructables.com/member/AhmadE2/?utm_source=pdf&utm_campaign=comments) says: | Feb 1, 2015. 8:25 AM REPLY (http://www.instructables.com/id/Arduino-Ublox-GPS/?utm_source=pdf&utm_campaign=comments#DISCUSS)
hi, i did everything you have done exactly but when i turn it on the LED that build-in on the GPS do not turn on and it say on the serial monitor "No GPS detected: check wiring."

what is the problem? and what i should do>

msuzuki777 (http://www.instructables.com/member/msuzuki777/?utm_source=pdf&utm_campaign=comments) says: | Feb 1, 2015. 10:25 AM REPLY (http://www.instructables.com/id/Arduino-Ublox-GPS/?utm_source=pdf&utm_campaign=comments#DISCUSS)
If the GPS module LED is not on than it sounds like you're not getting power to the GPS module. If you have a meter, measure the DC voltage on the Vcc pin to ground. If it's 3.3Vdc or 5Vdc then the module is probably bad. If it's 0Vdc, then check the wiring to the USB adapter.

If you don't have a voltmeter, check the wiring between the USB module and the GPS module, especially the Vcc and ground connections. It should work with Vcc connected to 5Vdc or 3.3Vdc.

Hopefully, this will help solve your problem. If the GPS module LED isn't on then it's not receiving power.

LOG

AhmadE2 (http://www.instructables.com/member/AhmadE2/?utm_source=pdf&utm_campaign=comments) says: | Feb 6, 2015. 9:21 AM REPLY (http://www.instructables.com/id/Arduino-Ublox-GPS/?utm_source=pdf&utm_campaign=comments#DISCUSS)
thanks :)
anouman (http://www.instructables.com/member/anouman/?utm_source=pdf&utm_campaign=comments) says: | Jan 4, 2015. 3:41 AM REPLY (http://www.instructables.com/id/Arduino-Ublox-GPS/?utm_source=pdf&utm_campaign=comments#DISCUSS)
Very useful thanks
comsa42 (http://www.instructables.com/member/comsa42/?utm_source=pdf&utm_campaign=comments) says: | Jun 11, 2014. 8:59 PM REPLY (http://www.instructables.com/id/Arduino-Ublox-GPS/?utm_source=pdf&utm_campaign=comments#DISCUSS)
U-center, Great Idea!
msuzuki777 (http://www.instructables.com/member/msuzuki777/?utm_source=pdf&utm_campaign=comments) says: | Jun 12, 2014. 4:46 AM REPLY (http://www.instructables.com/id/Arduino-Ublox-GPS/?utm_source=pdf&utm_campaign=comments#DISCUSS)
It's a nice program especially for freee.

LOG

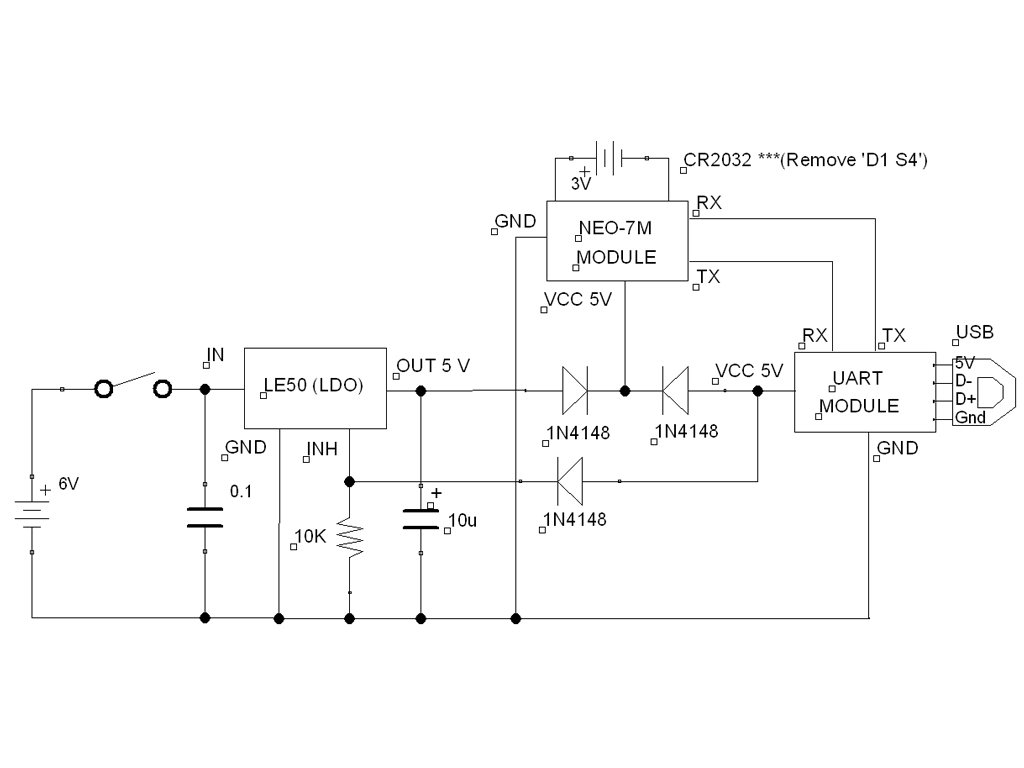
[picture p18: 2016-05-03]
gps/GPS+Battery+and+USB+Supply.png

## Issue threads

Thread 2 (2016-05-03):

GPS output

F6ITU, 2016-05-03:
non-wired/wrong  gps Output in the pcb

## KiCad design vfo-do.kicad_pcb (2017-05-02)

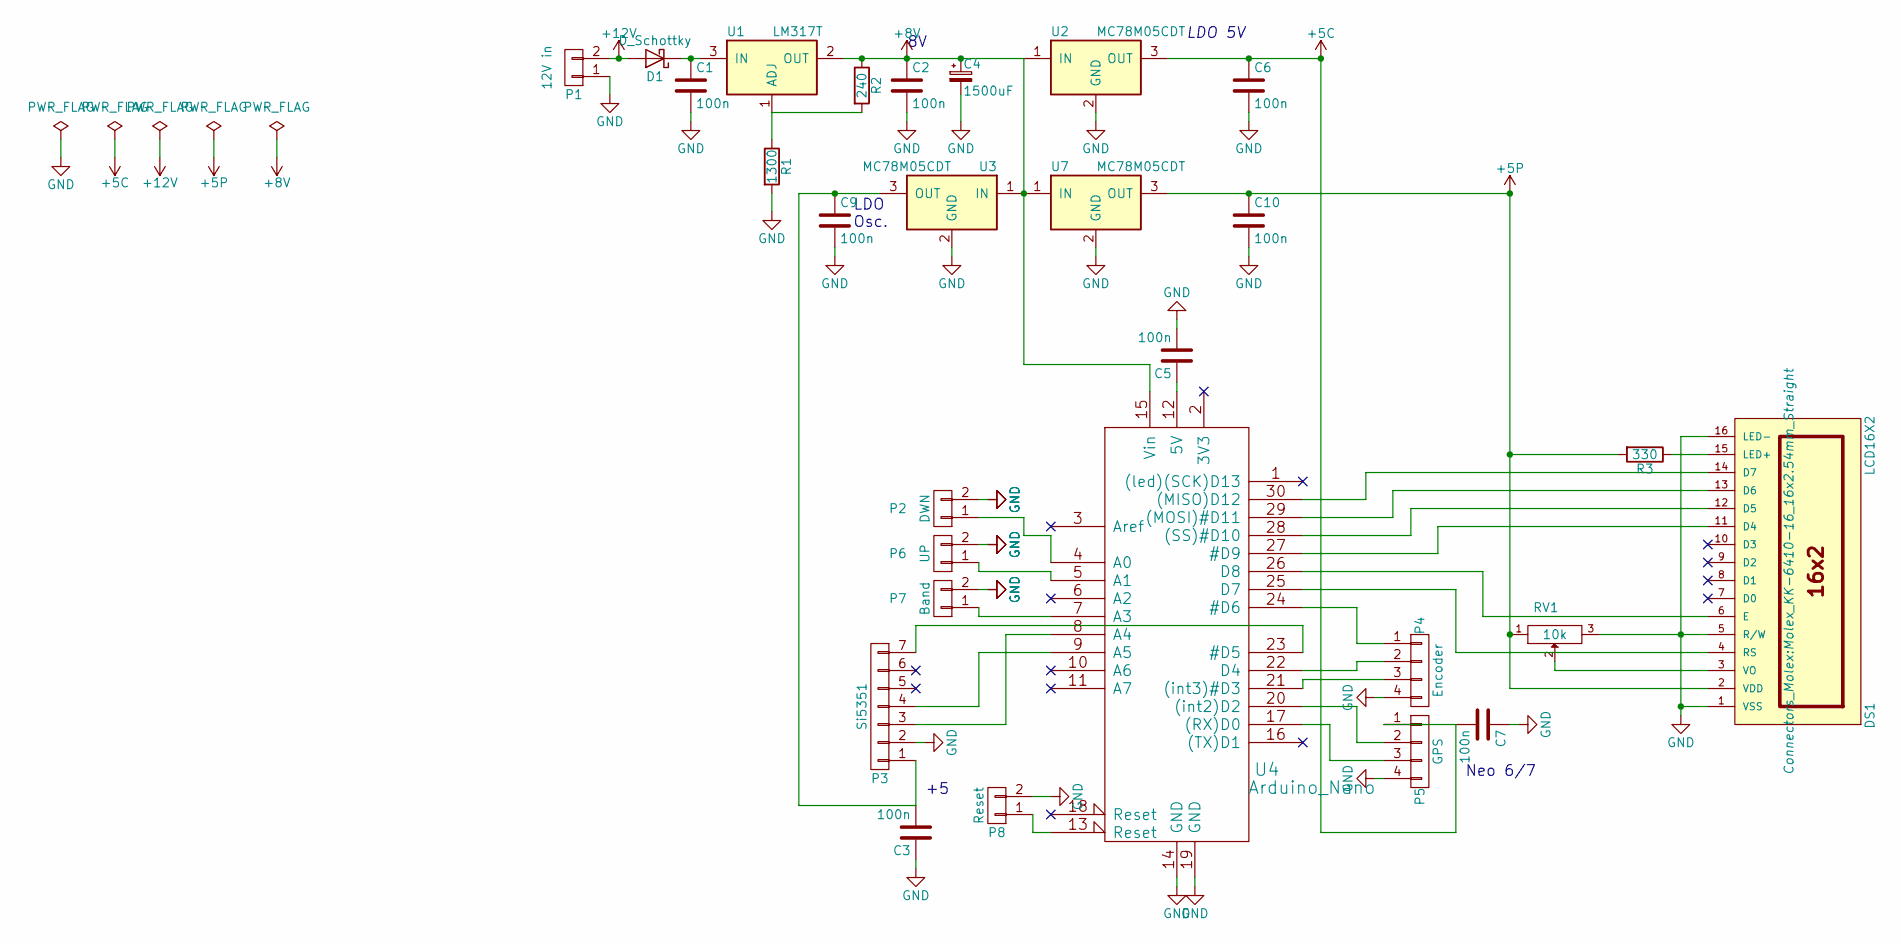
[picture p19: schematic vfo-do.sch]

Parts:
C1, C2, C3, C5, C6, C7, C9, C10: 100n; C_1206_HandSoldering
C4: 1500uF; c_elec_6.3x7.7
D1: D_Schottky; SMB_Handsoldering
DS1: LCD16X2; Molex_KK-6410-16_16x2.54mm_Straight
P1: 12V in; Molex_KK-6410-02_02x2.54mm_Straight
P2: DWN; Molex_KK-6410-02_02x2.54mm_Straight
P3: Si5351; Molex_KK-6410-07_07x2.54mm_Straight
P4: Encoder; Molex_KK-6410-04_04x2.54mm_Straight
P5: GPS; Molex_KK-6410-04_04x2.54mm_Straight
P6: UP; Molex_KK-6410-02_02x2.54mm_Straight
P7: Band; Molex_KK-6410-02_02x2.54mm_Straight
P8: Reset; Molex_KK-6410-02_02x2.54mm_Straight
R1: 1300; C_0805_HandSoldering
R2: 240; C_0805_HandSoldering
R3: 330; C_0805_HandSoldering
RV1: 10k; RV2X4
U1: LM317T; TO-220_Neutral123_Horizontal_LargePads
U2, U3, U7: MC78M05CDT; TO-252-2Lead
U4: Arduino_Nano; arduino_nano

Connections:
+5C: C6.1, C7.2, P5.1, U2.3 (OUT)
+5P: C10.1, DS1.2 (VDD), R3.2, RV1.1, U7.3 (OUT)
+8V: C2.1, C4.1, R2.1, U1.2 (OUT), U2.1 (IN), U3.1 (IN), U4.15 (Vin), U7.1 (IN)
+12V: D1.2 (A), P1.2
GND: C1.2, C2.2, C3.1, C4.2, C5.2, C6.2, C7.1, C9.2, C10.2, DS1.1 (VSS), DS1.5 (R/W), DS1.16 (LED-), P1.1, P2.2, P3.2, P4.4, P5.4, P6.2, P7.2, P8.2, R1.2, RV1.3, U2.2 (GND), U3.2 (GND), U4.14 (GND), U4.19 (GND), U7.2 (GND)
unnamed: C1.1, D1.1 (K), U1.3 (IN)
unnamed: C3.2, C9.1, P3.1, U3.3 (OUT)
unnamed: C5.1, U4.12 (5V)
unnamed: DS1.3 (VO), RV1.2
unnamed: DS1.4 (RS), U4.25 (D7)
unnamed: DS1.6 (E), U4.26 (D8)
unnamed: DS1.11 (D4), U4.27 (#D9)
unnamed: DS1.12 (D5), U4.28 ((SS)#D10)
unnamed: DS1.13 (D6), U4.29 ((MOSI)#D11)
unnamed: DS1.14 (D7), U4.30 ((MISO)D12)
unnamed: DS1.15 (LED+), R3.1
unnamed: P2.1, U4.4 (A0)
unnamed: P3.3, U4.8 (A4)
unnamed: P3.4, U4.9 (A5)
unnamed: P3.7, U4.23 (#D5)
unnamed: P4.1, U4.24 (#D6)
unnamed: P4.2, U4.22 (D4)
unnamed: P4.3, U4.21 ((int3)#D3)
unnamed: P5.2, U4.20 ((int2)D2)
unnamed: P5.3, U4.17 ((RX)D0)
unnamed: P6.1, U4.5 (A1)
unnamed: P7.1, U4.7 (A3)
unnamed: P8.1, U4.13 (Reset)
unnamed: R1.1, R2.2, U1.1 (ADJ)

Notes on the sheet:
LDO Osc.
Neo 6/7
LDO 5V

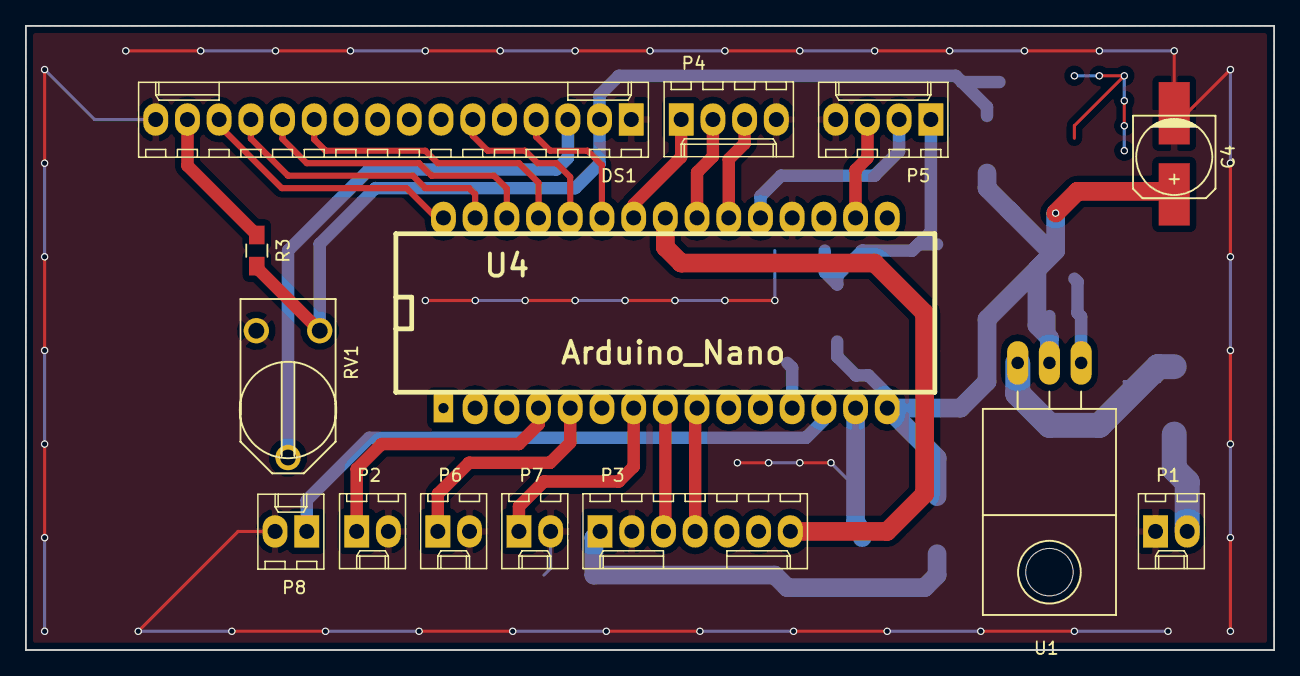
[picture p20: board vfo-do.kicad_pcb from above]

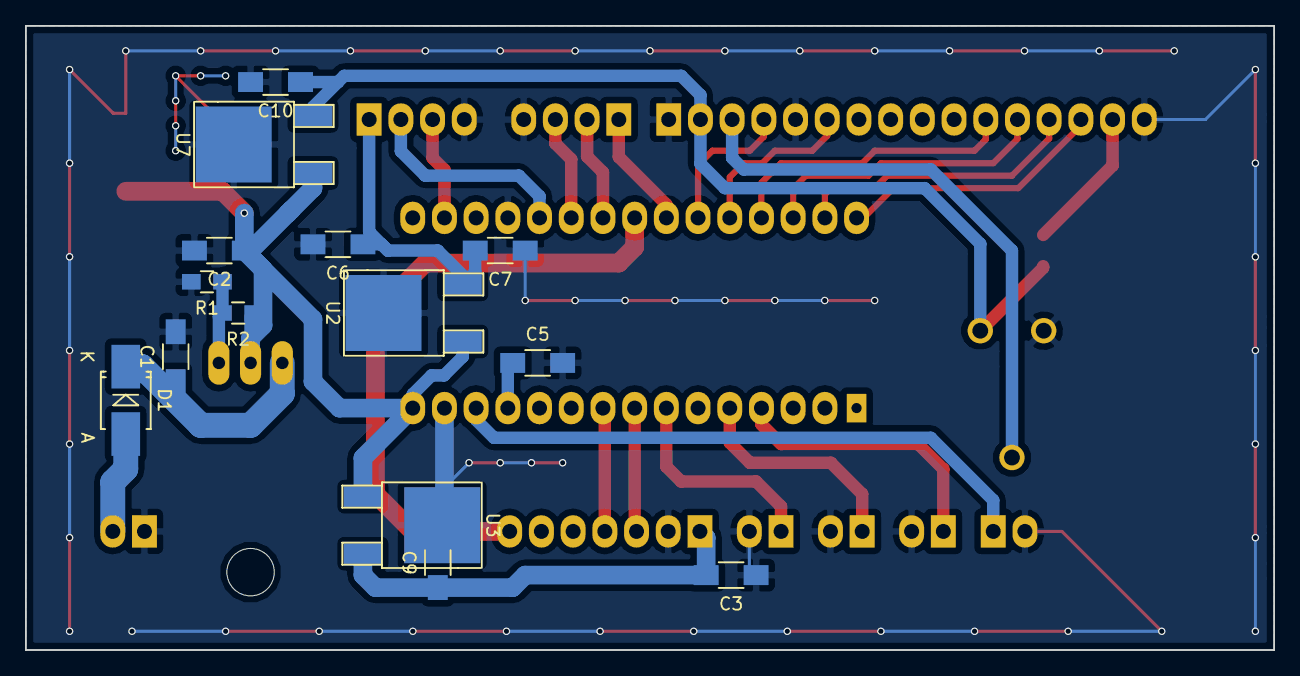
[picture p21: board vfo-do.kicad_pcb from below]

Board: 2 copper layers, 100.0 x 50.0 mm, 28 parts (14 on the bottom side), 29 nets.

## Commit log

2016-05-03 branche originelle du projet VFO-DO
    [vfo-do.kicad_pcb, vfo-do.sch]
2016-05-03 modif du rappel de masse d'un rétulateur 5V
    [vfo-do.kicad_pcb]
2016-05-04 modif mineure sur un rappel de masse
    [vfo-do.sch]
2017-05-02 suppression des sorties filtres
    [vfo-do.kicad_pcb, vfo-do.sch]
2017-05-02 nettoyage routage, LM317 et Si5351 non verifie
    [vfo-do.kicad_pcb, vfo-do.sch]
